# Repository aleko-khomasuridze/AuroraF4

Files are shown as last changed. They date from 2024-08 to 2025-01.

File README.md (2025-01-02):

# AuroraF4

AuroraF4 is a powerful development board based on the STM32F407VGT microcontroller, designed to provide developers with a feature-rich and compact solution for embedded system projects. This board is equipped with multiple peripherals, GPIOs, and expansion headers, making it ideal for both beginners and professionals.

## Features

- **Microcontroller**: STM32F407VGT
  - ARM Cortex-M4 processor
  - 168 MHz clock speed
  - 1 MB Flash, 192 KB SRAM
- **Interfaces**:
  - SPI, I2C, USART
  - JTAG/SWD debugging support
- **Peripherals**:
  - User-configurable LEDs (Green, Red, Yellow, Blue)
  - Reset (RST) and User (USR) buttons
  - Power input via USB-C or barrel jack
- **Expansion**:
  - Pin headers for GPIO access
  - 3.3V and GND pins available for peripherals
- **Power**:
  - Powered via USB-C or external 12V input

## Pinout Diagram

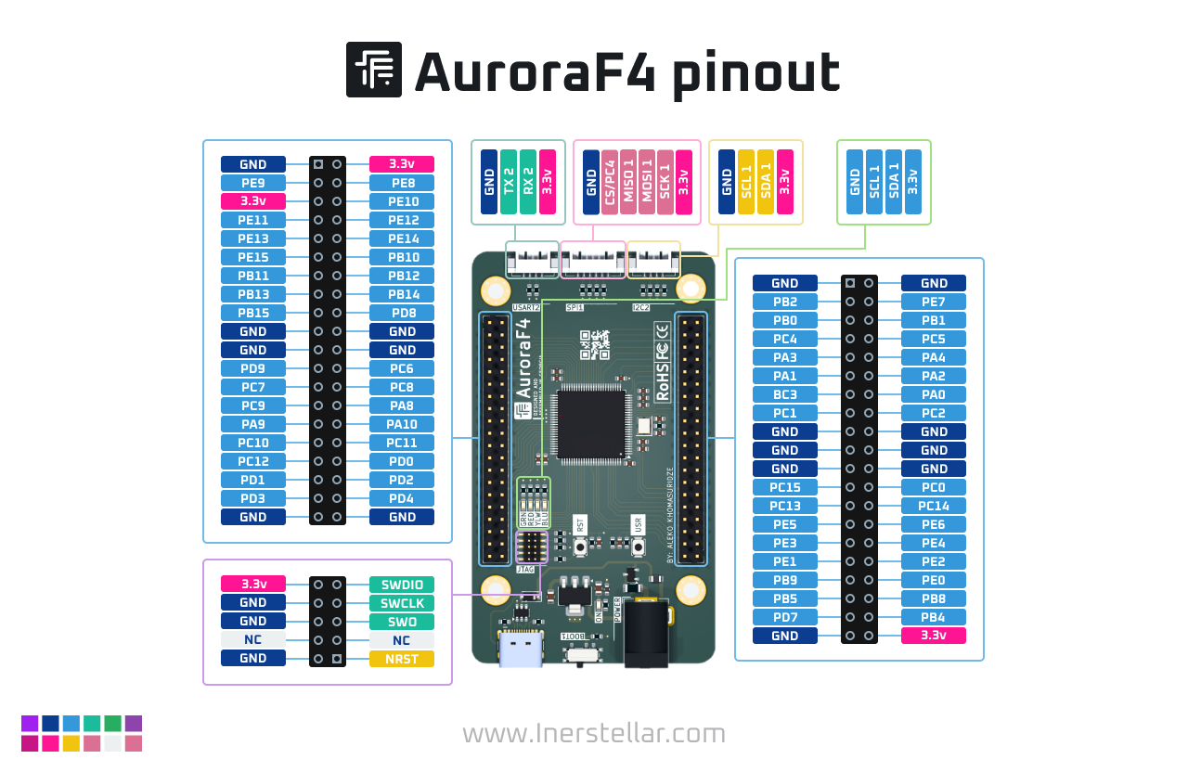
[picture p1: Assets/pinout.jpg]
AuroraF4 Pinout


Refer to the pinout diagram above for GPIO assignments and interface connections.

## PCB Design and Layout

### PCB Top View
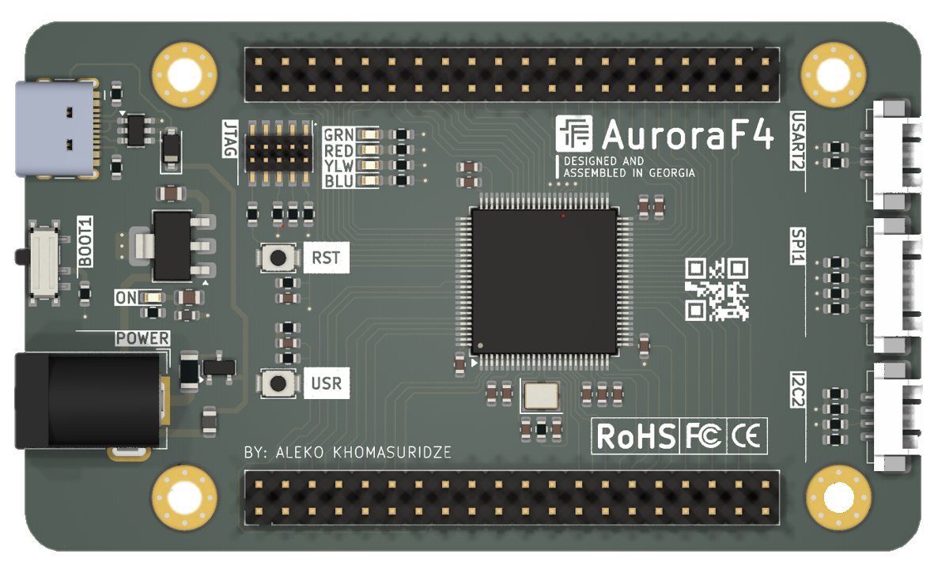
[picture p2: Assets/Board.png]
AuroraF4 PCB Layout


### 3D Render
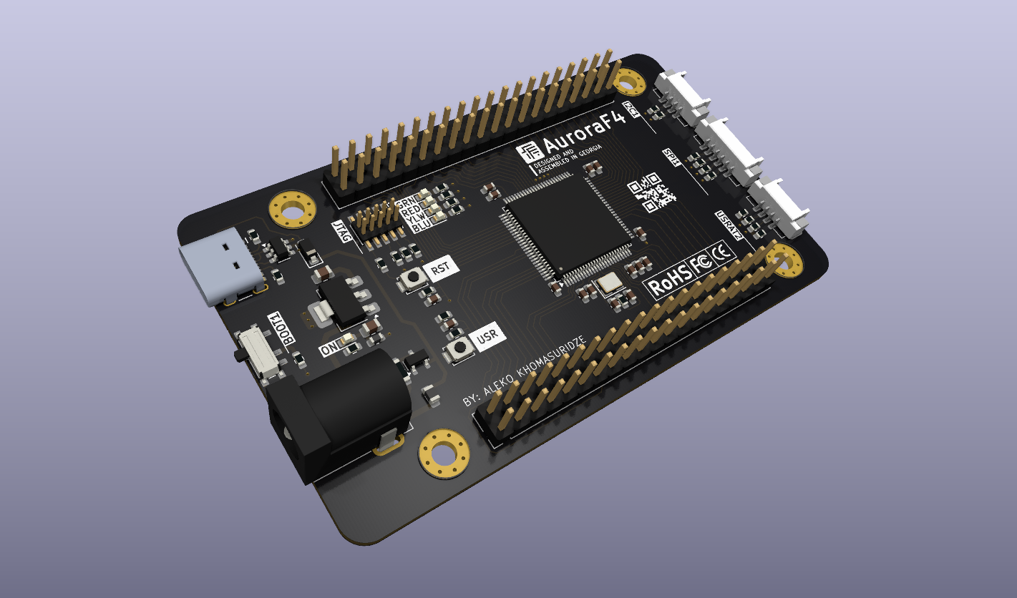
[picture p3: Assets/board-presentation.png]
AuroraF4 Render


## Getting Started

### Prerequisites

- Install [STM32CubeIDE](https://www.st.com/en/development-tools/stm32cubeide.html) for firmware development.
- Set up the STM32CubeMX tool for peripheral configuration.

### Powering the Board

1. Connect a USB-C cable to the power port.
2. Alternatively, use a 12V adapter through the barrel jack.

### Flashing Code

1. Connect the board to   your computer via USB.
2. Open STM32CubeIDE, configure your project for the STM32F407VGT.
3. Build and flash your program to the board.

### Debugging

Use the JTAG/SWD interface for debugging and programming. Ensure you have a compatible debugger like ST-Link V2.

## Applications

AuroraF4 is suitable for:
- Embedded systems prototyping
- IoT projects
- Robotics and automation
- Learning and experimentation with ARM Cortex-M4 architecture

## Resources

- [STM32F407VGT Datasheet](https://www.st.com/resource/en/datasheet/stm32f407vg.pdf)
- [STM32CubeIDE](https://www.st.com/en/development-tools/stm32cubeide.html)
- Pinout and Schematic: Refer to the `pinout.jpg` and PCB layout images in this repository.

## Credits

AuroraF4 is designed and assembled in Georgia by Aleko Khomasuridze.

---

For questions, suggestions, or contributions, feel free to open an issue or reach out.

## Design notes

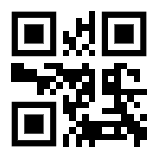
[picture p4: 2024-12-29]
Assets/Screenshot 2024-10-15 233057.png

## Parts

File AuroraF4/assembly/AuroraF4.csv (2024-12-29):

Designator | Comment | Footprint | JLCPCB Part # | Available | Orders
BOOT1 | SW_SPDT | Button_Switch_SMD:SW_SPDT_PCM12 | C221841
C1 | 4u7 | Capacitor_SMD:C_0603_1608Metric | C1705
C2,C3 | 2u2 | Capacitor_SMD:C_0603_1608Metric | C23630
C4,C5,C6,C7,C8,C9,C17,C18 | 100n | Capacitor_SMD:C_0603_1608Metric | C14663
C10 | 1u | Capacitor_SMD:C_0603_1608Metric | C1592
C11 | 10n | Capacitor_SMD:C_0603_1608Metric | C100042
C12,C13 | 12p | Capacitor_SMD:C_0603_1608Metric | C107034
C14 | 10u | Capacitor_SMD:C_0805_2012Metric | C5189822
C15 | 22u | Capacitor_SMD:C_0805_2012Metric | C29277
D1 | BLUE | LED_SMD:LED_0603_1608Metric | C72041
D2 | RED | LED_SMD:LED_0603_1608Metric | C72044
D3 | YELLOW | LED_SMD:LED_0603_1608Metric | C72038
D4,D5 | GREEN | LED_SMD:LED_0603_1608Metric | C72043
D6 | 1N4148WT | Diode_SMD:D_SOD-123 | C963381
F1 | 250mA | Fuse:Fuse_1206_3216Metric | C135328
FB1 | 600 @ 600MHz | Inductor_SMD:L_0805_2012Metric | C1017
J1 | SPI_1 | Connector_JST_XA_1.25mm:JST-XA-1.25mm SMD Horizontal 01x06
J2 | SWD | Connector_PinHeader_1.27mm:PinHeader_2x05_P1.27mm_Vertical_SMD | C598540
J3 | I2C_1 | Connector_JST_XA_1.25mm:JST-XA-1.25mm SMD Horizontal 01x04
J4 | USART_2 | Connector_JST_XA_1.25mm:JST-XA-1.25mm SMD Horizontal 01x04
J5 | USB_C_Receptacle_USB2.0_16P | USB_TYPE_C:USB_C_Receptacle_HCTL_HC-TYPE-C-16P-01A | C39832533
J7,J9 | Conn_02x20_Odd_Even | Connector_PinHeader_2.54mm:PinHeader_2x20_P2.54mm_Vertical
L1 | 39n | Inductor_SMD:L_0603_1608Metric | C74308
POWER | Barrel_Jack_MountingPin | Connector_DC_Jack:BarrelJack_GCT_DCJ200-10-A_Horisontal | C319099
Q1 | AO3401A | Package_TO_SOT_SMD:SOT-23 | C347476
R1 | 10k | Resistor_SMD:R_0603_1608Metric | C25804
R2 | 47r | Resistor_SMD:R_0603_1608Metric | C23182
R4,R5 | 4.7k | Resistor_SMD:R_0603_1608Metric | C105428
R6 | 100R | Resistor_SMD:R_0603_1608Metric | C23345
R7,R8,R9,R10,R13,R14,R15,R16,R20,R21,R22,R23 | 22r | Resistor_SMD:R_0603_1608Metric | C23345
R11,R12 | 2.2k | Resistor_SMD:R_0603_1608Metric | C4190
R17,R18 | 5.1k | Resistor_SMD:R_0603_1608Metric | C23186
R19 | 330r | Resistor_SMD:R_0603_1608Metric | C23138
R24,R25,R26,R27 | 1k | Resistor_SMD:R_0603_1608Metric | C25804
RST | SW_Push | Button_Switch_SMD:SW_SPST_B3U-1000P | C843666
U1 | STM32F407VGTx | Package_QFP:LQFP-100_14x14mm_P0.5mm | C12345
U3 | USBLC6-2SC6 | Package_TO_SOT_SMD:SOT-23-6 | C7519
U4 | AMS1117-3.3 | Package_TO_SOT_SMD:SOT-223-3_TabPin2 | C347222
USR | SW_Push | Button_Switch_SMD:SW_SPST_B3U-1000P | C843666
Y1 | 16MHz | Crystal:Crystal_SMD_3225-4Pin_3.2x2.5mm | C5917307

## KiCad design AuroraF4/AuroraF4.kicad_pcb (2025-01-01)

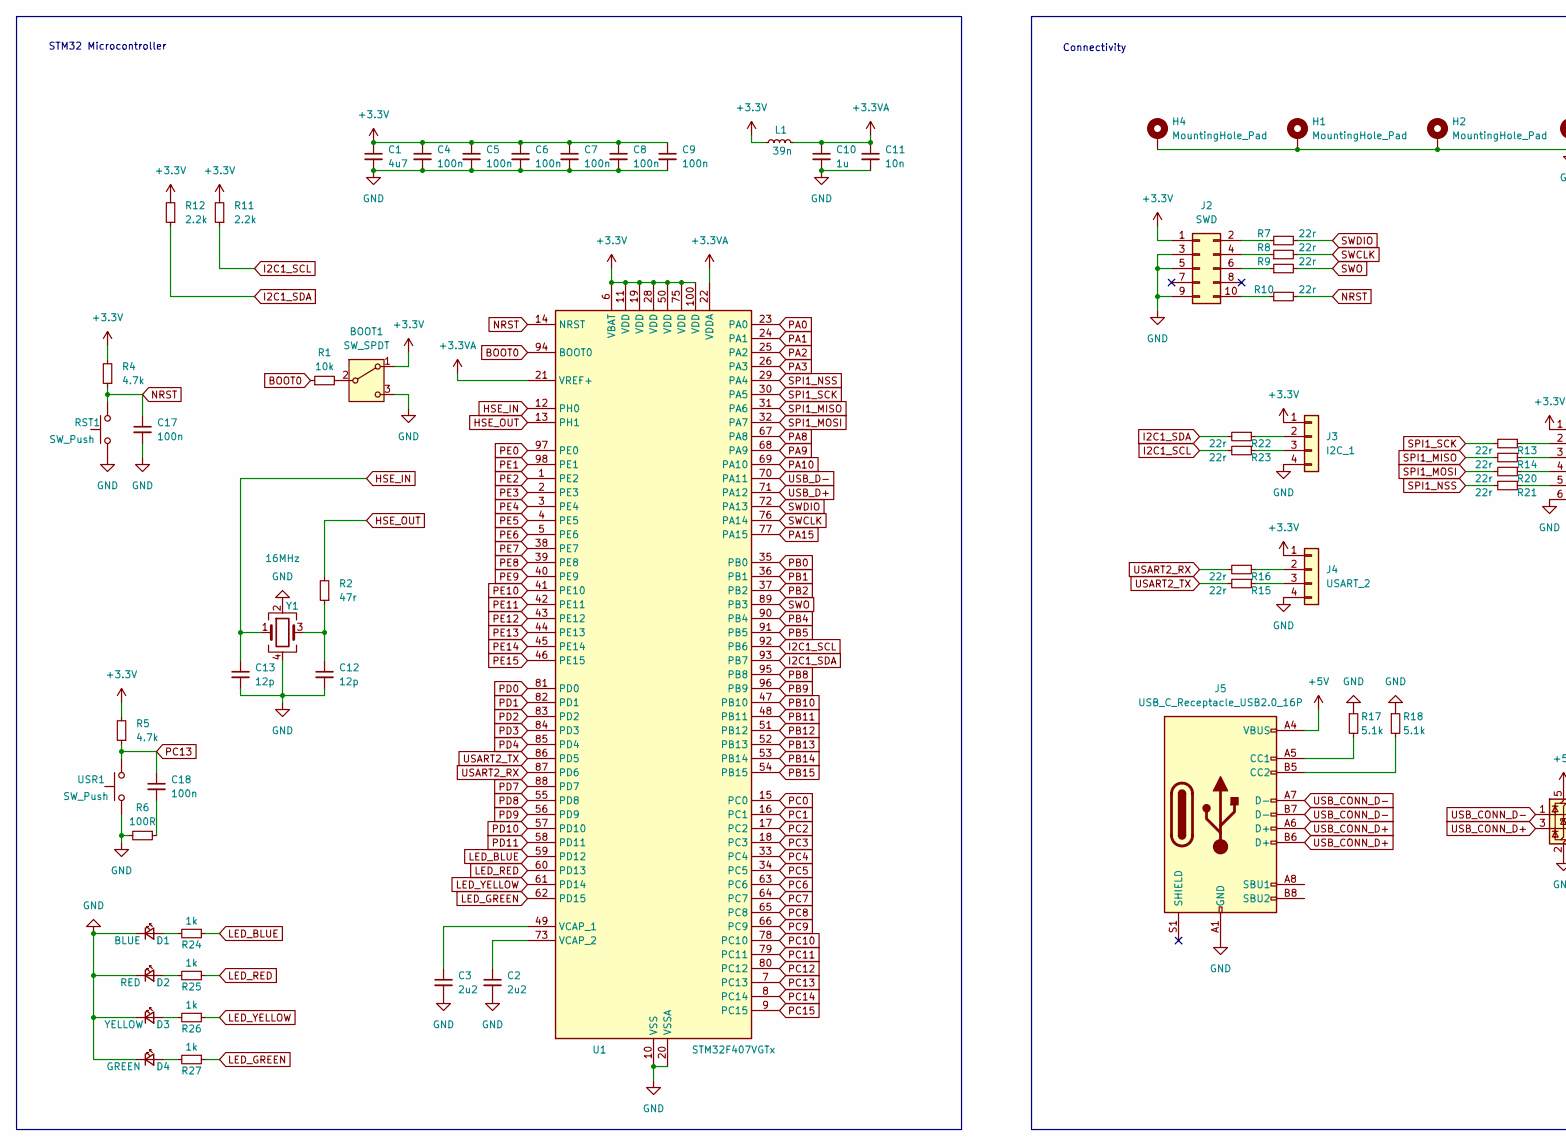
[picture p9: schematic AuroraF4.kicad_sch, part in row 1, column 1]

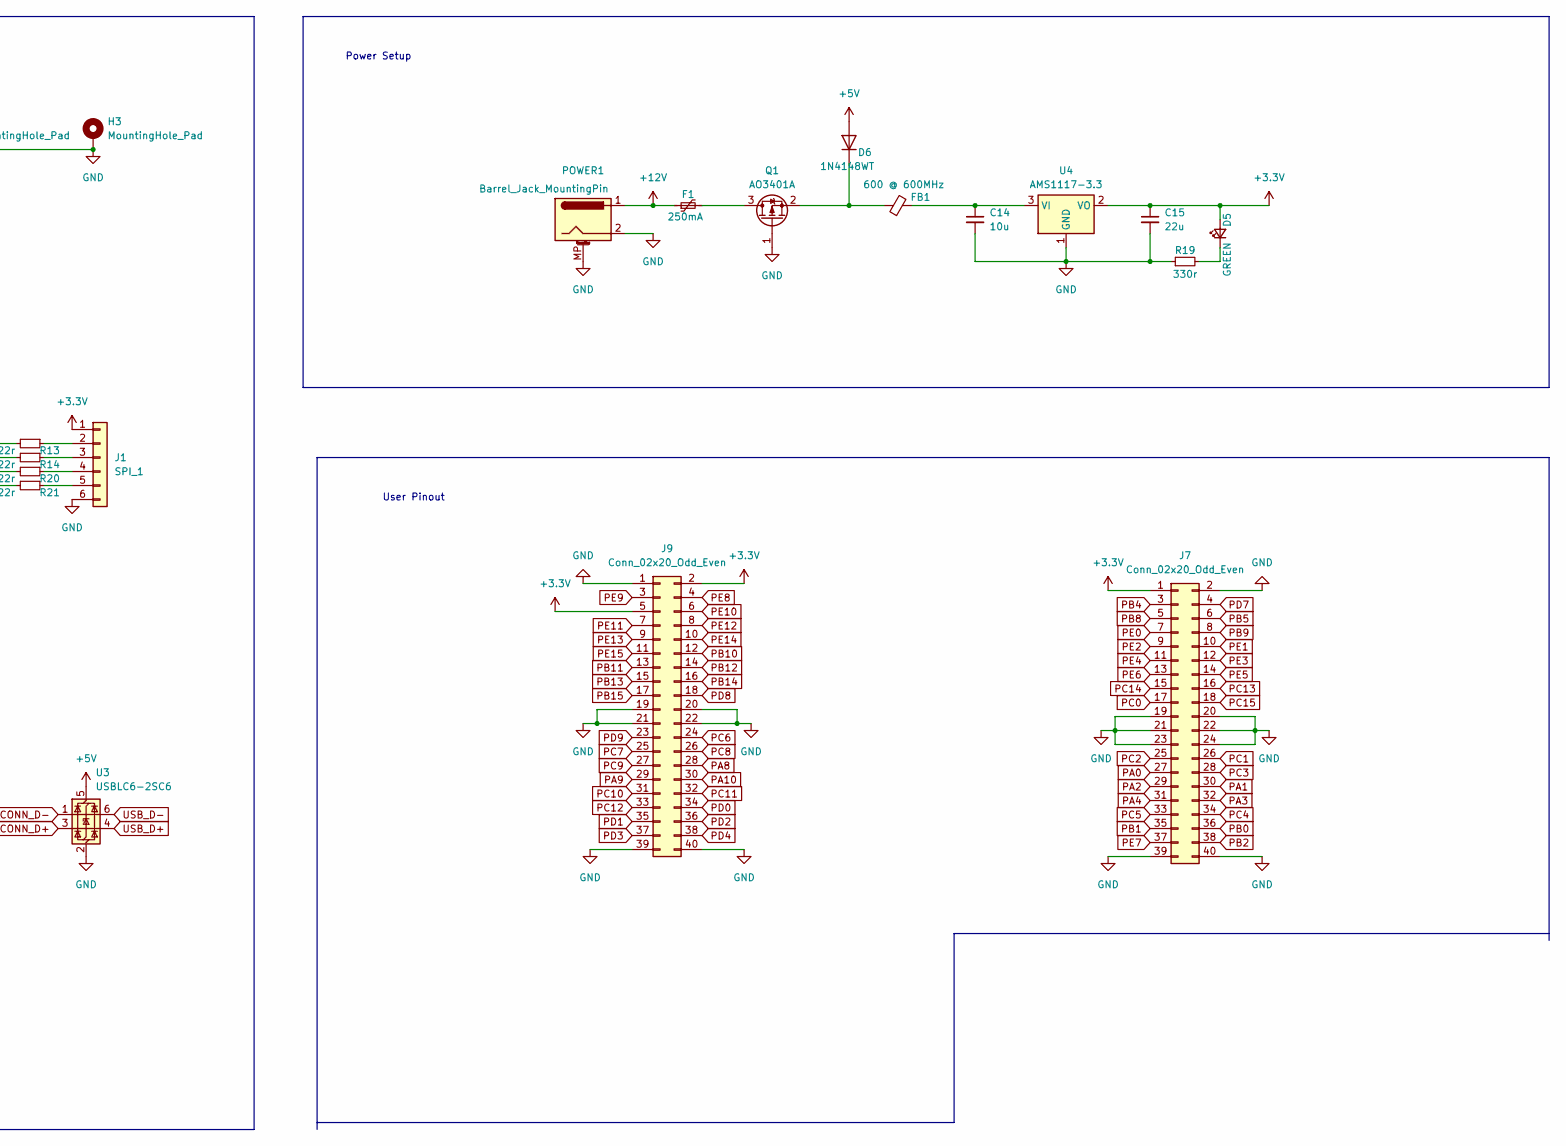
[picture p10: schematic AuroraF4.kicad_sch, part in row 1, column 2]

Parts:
BOOT1: SW_SPDT; SW_SPDT_PCM12; LCSC Part # C221841
C1: 4u7; C_0603_1608Metric; LCSC Part # C1705
C2, C3: 2u2; C_0603_1608Metric; LCSC Part # C23630
C4, C5, C6, C7, C8, C9, C17, C18: 100n; C_0603_1608Metric; LCSC Part # C14663
C10: 1u; C_0603_1608Metric; LCSC Part # C1592
C11: 10n; C_0603_1608Metric; LCSC Part # C100042
C12, C13: 12p; C_0603_1608Metric; LCSC Part # C107034
C14: 10u; C_0805_2012Metric; LCSC Part # C5189822
C15: 22u; C_0805_2012Metric; LCSC Part # C29277
D1: BLUE; LED_0603_1608Metric; LCSC Part # C72041
D2: RED; LED_0603_1608Metric; LCSC Part # C72044
D3: YELLOW; LED_0603_1608Metric; LCSC Part # C72038
D4, D5: GREEN; LED_0603_1608Metric; LCSC Part # C72043
D6: 1N4148WT; D_SOD-123; LCSC Part # C963381
F1: 250mA; Fuse_1206_3216Metric; LCSC Part # C135328
FB1: 600 @ 600MHz; L_0805_2012Metric; LCSC Part # C1017
H1, H2, H3, H4: MountingHole_Pad; MountingHole_3.2mm_M3_Pad_Via
J1: SPI_1; JST-XA-1.25mm SMD Horizontal 01x06
J2: SWD; PinHeader_2x05_P1.27mm_Vertical_SMD; LCSC Part # C598540
J3: I2C_1; JST-XA-1.25mm SMD Horizontal 01x04
J4: USART_2; JST-XA-1.25mm SMD Horizontal 01x04
J5: USB_C_Receptacle_USB2.0_16P; USB_C_Receptacle_HCTL_HC-TYPE-C-16P-01A; LCSC Part # C39832533
J7, J9: Conn_02x20_Odd_Even; PinHeader_2x20_P2.54mm_Vertical
L1: 39n; L_0603_1608Metric; LCSC Part # C74308
POWER1: Barrel_Jack_MountingPin; BarrelJack_GCT_DCJ200-10-A_Horisontal; LCSC Part # C319099
Q1: AO3401A; SOT-23; LCSC Part # C347476
R1: 10k; R_0603_1608Metric; LCSC Part # C25804
R2: 47r; R_0603_1608Metric; LCSC Part # C23182
R4, R5: 4.7k; R_0603_1608Metric; LCSC Part # C105428
R6: 100R; R_0603_1608Metric; LCSC Part # C23345
R7, R8, R9, R10, R13, R14, R15, R16, R20, R21, R22, R23: 22r; R_0603_1608Metric; LCSC Part # C23345
R11, R12: 2.2k; R_0603_1608Metric; LCSC Part # C4190
R17, R18: 5.1k; R_0603_1608Metric; LCSC Part # C23186
R19: 330r; R_0603_1608Metric; LCSC Part # C23138
R24, R25, R26, R27: 1k; R_0603_1608Metric; LCSC Part # C25804
RST1: SW_Push; SW_SPST_B3U-1000P; LCSC Part # C843666
U1: STM32F407VGTx; LQFP-100_14x14mm_P0.5mm; LCSC Part # C12345
U3: USBLC6-2SC6; SOT-23-6; LCSC Part # C7519
U4: AMS1117-3.3; SOT-223-3_TabPin2; LCSC Part # C347222
USR1: SW_Push; SW_SPST_B3U-1000P; LCSC Part # C843666
Y1: 16MHz; Crystal_SMD_3225-4Pin_3.2x2.5mm; LCSC Part # C5917307

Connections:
+3.3V: BOOT1.1 (A), C1.1, C4.1, C5.1, C6.1, C7.1, C8.1, C9.1, C15.1, D5.2 (A), J1.1, J2.1, J3.1, J4.1, J7.1, J9.2, J9.5, L1.1, R4.2, R5.2, R11.2, R12.2, U1.6 (VBAT), U1.11 (VDD), U1.19 (VDD), U1.28 (VDD), U1.50 (VDD), U1.75 (VDD), U1.100 (VDD), U4.2 (VO)
+3.3VA: C10.1, C11.1, L1.2, U1.21 (VREF+), U1.22 (VDDA)
+5V: D6.2 (A), J5.A4 (VBUS), J5.A9 (VBUS), J5.B4 (VBUS), J5.B9 (VBUS), U3.5 (VBUS)
+12V: F1.1, POWER1.1; also elsewhere on the board
BOOT0: R1.1, U1.94 (BOOT0)
GND: BOOT1.3 (C), C1.2, C2.2, C3.2, C4.2, C5.2, C6.2, C7.2, C8.2, C9.2, C10.2, C11.2, C12.2, C13.2, C14.2, C15.2, C17.2, D1.1 (K), D2.1 (K), D3.1 (K), D4.1 (K), H1.1, H2.1, H3.1, H4.1, J1.6, J2.3, J2.5, J2.9, J3.4, J4.4, J5.A1 (GND), J5.A12 (GND), J5.B1 (GND), J5.B12 (GND), J7.2, J7.19, J7.20, J7.21, J7.22, J7.23, J7.24, J7.39, J7.40, J9.1, J9.19, J9.20, J9.21, J9.22, J9.39, J9.40, POWER1.2, POWER1.MP (MountPin), Q1.1 (G), R6.2, R17.1, R18.1, R19.1, RST1.1, U1.10 (VSS), U1.20 (VSSA), U1.27 (VSS), U1.74 (VSS), U1.99 (VSS), U3.2 (GND), U4.1 (GND), USR1.1, Y1.2, Y1.4; also elsewhere on the board
HSE_IN: C13.1, U1.12 (PH0), Y1.1
HSE_OUT: R2.2, U1.13 (PH1)
I2C1_SCL: R11.1, R23.2, U1.92 (PB6)
I2C1_SDA: R12.1, R22.2, U1.93 (PB7)
LED_BLUE: R24.1, U1.59 (PD12)
LED_GREEN: R27.1, U1.62 (PD15)
LED_RED: R25.1, U1.60 (PD13)
LED_YELLOW: R26.1, U1.61 (PD14)
NRST: C17.1, R4.1, R10.2, RST1.2, U1.14 (NRST); also elsewhere on the board
unnamed: BOOT1.2 (B), R1.2
unnamed: C12.1, R2.1, Y1.3
unnamed: C18.2, R6.1
unnamed: D1.2 (A), R24.2
unnamed: D2.2 (A), R25.2
unnamed: D3.2 (A), R26.2
unnamed: D4.2 (A), R27.2
unnamed: D5.1 (K), R19.2
unnamed: D6.1 (K), FB1.1, Q1.2 (S)
unnamed: J1.2, R13.1
unnamed: J1.3, R14.1
unnamed: J1.4, R20.1
unnamed: J1.5, R21.1
unnamed: J2.2, R7.1
unnamed: J2.4, R8.1
unnamed: J2.6, R9.1
unnamed: J2.10, R10.1
unnamed: J3.2, R22.1
unnamed: J3.3, R23.1
unnamed: J4.2, R16.1
unnamed: J4.3, R15.1
unnamed: J5.A5 (CC1), R17.2
unnamed: J5.B5 (CC2), R18.2
unnamed: F1.2, Q1.3 (D)
unnamed: C3.1, U1.49 (VCAP_1)
unnamed: C2.1, U1.73 (VCAP_2)
unnamed: C14.1, FB1.2, U4.3 (VI)
PA0: J7.27, U1.23 (PA0)
PA1: J7.30, U1.24 (PA1)
PA2: J7.29, U1.25 (PA2)
PA3: J7.32, U1.26 (PA3)
PA4: J7.31
PA8: J9.28, U1.67 (PA8)
PA9: J9.29, U1.68 (PA9)
PA10: J9.30, U1.69 (PA10)
PA15: U1.77 (PA15)
PB0: J7.36, U1.35 (PB0)
PB1: J7.35, U1.36 (PB1)
PB2: J7.38, U1.37 (PB2)
PB4: J7.3, U1.90 (PB4)
PB5: J7.6, U1.91 (PB5)
PB8: J7.5, U1.95 (PB8)
PB9: J7.8, U1.96 (PB9)
PB10: J9.12, U1.47 (PB10)
PB11: J9.13, U1.48 (PB11)
PB12: J9.14, U1.51 (PB12)
PB13: J9.15, U1.52 (PB13)
PB14: J9.16, U1.53 (PB14)
PB15: J9.17, U1.54 (PB15)
PC0: J7.17, U1.15 (PC0)
PC1: J7.26, U1.16 (PC1)
PC2: J7.25, U1.17 (PC2)
PC3: J7.28, U1.18 (PC3)
PC4: J7.34, U1.33 (PC4)
PC5: J7.33, U1.34 (PC5)
PC6: J9.24, U1.63 (PC6)
PC7: J9.25, U1.64 (PC7)
PC8: J9.26, U1.65 (PC8)
PC9: J9.27, U1.66 (PC9)
PC10: J9.31, U1.78 (PC10)
PC11: J9.32, U1.79 (PC11)
PC12: J9.33, U1.80 (PC12)
PC13: C18.1, J7.16, R5.1, U1.7 (PC13), USR1.2; also elsewhere on the board
PC14: J7.15, U1.8 (PC14)
PC15: J7.18, U1.9 (PC15)
PD0: J9.34, U1.81 (PD0)
PD1: J9.35, U1.82 (PD1)
PD2: J9.36, U1.83 (PD2)
PD3: J9.37, U1.84 (PD3)
PD4: J9.38, U1.85 (PD4)
PD7: J7.4, U1.88 (PD7)
PD8: J9.18, U1.55 (PD8)
PD9: J9.23, U1.56 (PD9)
PD10: U1.57 (PD10)
PD11: U1.58 (PD11)
PE0: J7.7, U1.97 (PE0)
PE1: J7.10, U1.98 (PE1)
PE2: J7.9, U1.1 (PE2)
PE3: J7.12, U1.2 (PE3)
PE4: J7.11, U1.3 (PE4)
PE5: J7.14, U1.4 (PE5)
PE6: J7.13, U1.5 (PE6)
PE7: J7.37, U1.38 (PE7)
PE8: J9.4, U1.39 (PE8)
PE9: J9.3, U1.40 (PE9)
PE10: J9.6, U1.41 (PE10)
PE11: J9.7, U1.42 (PE11)
PE12: J9.8, U1.43 (PE12)
PE13: J9.9, U1.44 (PE13)
PE14: J9.10, U1.45 (PE14)
PE15: J9.11, U1.46 (PE15)
SPI1_MISO: R14.2, U1.31 (PA6)
SPI1_MOSI: R20.2, U1.32 (PA7)
SPI1_NSS: R21.2, U1.29 (PA4)
SPI1_SCK: R13.2, U1.30 (PA5)
SWCLK: R8.2, U1.76 (PA14)
SWDIO: R7.2, U1.72 (PA13)
SWO: R9.2, U1.89 (PB3)
USART2_RX: R16.2, U1.87 (PD6)
USART2_TX: R15.2, U1.86 (PD5)
USB_CONN_D+: J5.A6 (D+), J5.B6 (D+), U3.3 (I/O2)
USB_CONN_D-: J5.A7 (D-), J5.B7 (D-), U3.1 (I/O1)
USB_D+: U1.71 (PA12), U3.4 (I/O2)
USB_D-: U1.70 (PA11), U3.6 (I/O1)

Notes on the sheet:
Power Setup
STM32 Microcontroller
Connectivity
User Pinout

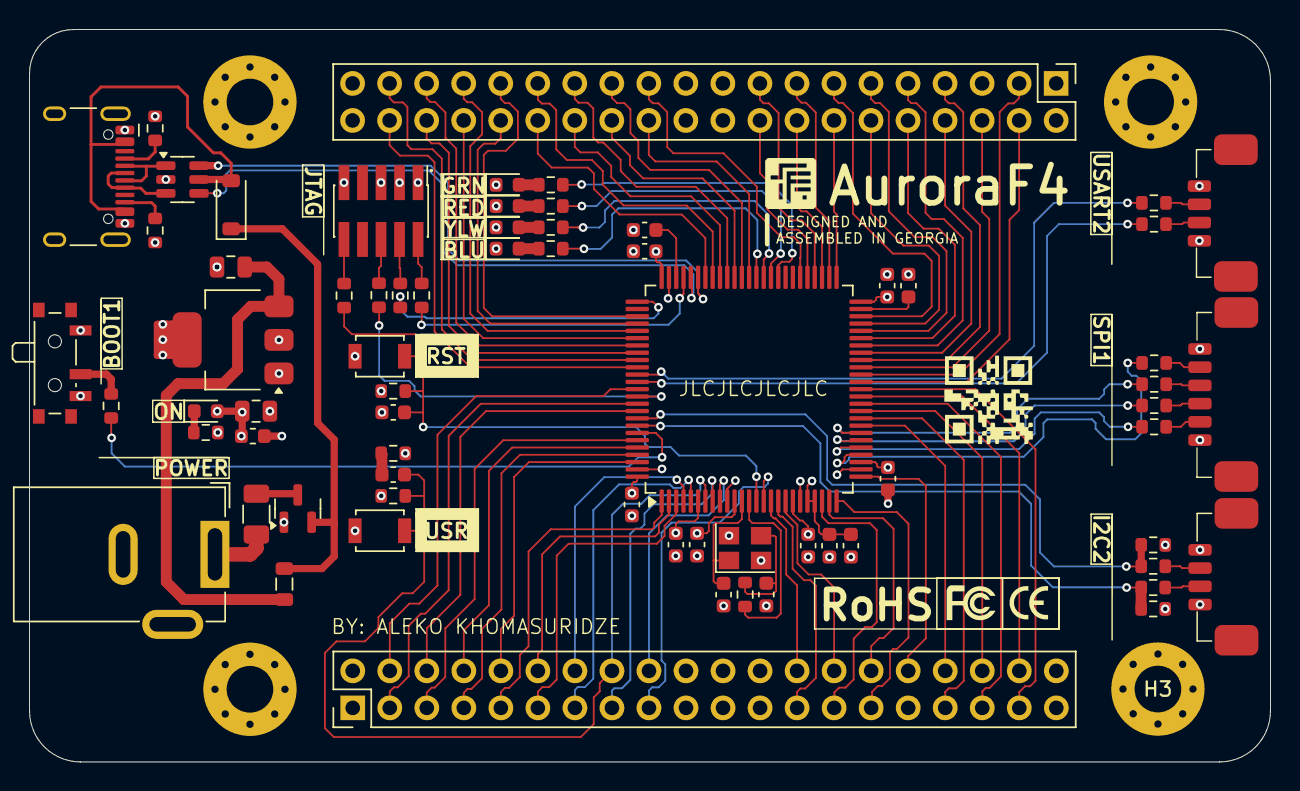
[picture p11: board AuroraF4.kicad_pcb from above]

Board: 4 copper layers, 85.1 x 50.2 mm, 72 parts (0 on the bottom side), 115 nets.

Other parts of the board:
POWER: Barrel_Jack_MountingPin; BarrelJack_GCT_DCJ200-10-A_Horisontal
RST: SW_Push; SW_SPST_B3U-1000P
USR: SW_Push; SW_SPST_B3U-1000P

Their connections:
+12V: POWER.1; also elsewhere on the board
GND: POWER.2, RST.1, USR.1; also elsewhere on the board
NRST: RST.2; also elsewhere on the board
PC13: USR.2; also elsewhere on the board

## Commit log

2024-08-04 initilized PCB Prj
    [AuroraF4_v1.0.0.PrjPcb, LQFP100-14x14mm.step, QFP50P1600X1600X160-100N.PcbLib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]
2024-08-07 Added reset boot I2C, SPI, UART, ETH to Sch
    [main.SchDoc]
2024-08-07 added indicator lights to uart
    [0603 Blue.step, main.SchDoc]
2024-08-08 added Indicator LED and 2x20 male header to Sch
    [2x20_Male_Header.step, AuroraF4_v1.0.0.PrjPcb, main.SchDoc]
2024-08-08 PCB Update
    [main.SchDoc]
2024-08-10 added stlink support to Sch and fixed layout of components on PCB
    [User Library-2_54mm Male Header (4x2).STEP, main.SchDoc]
2024-08-10 createdd logo for board
2024-08-10 added some silk screen decorations to PCB
    [main.SchDoc]
2024-08-11 started routing traces
    [main.SchDoc]
2024-08-11 finished routing all the tracks
    [main.SchDoc]
2024-08-12 started adding polygons to PCB and fixed some silk screen
2024-08-12 added silk screens on the top of the board
2024-08-13 finalized board v1.0.0
    [main.GBL, main.GBO, main.GBP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]
2024-08-13 fixed USB-C pads
    [AuroraF4_v1.0.0.PrjPcb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]
2024-08-22 updated pcb and generated bom file
    [main.SchDoc]
2024-12-29 complete AuroraF4 Board refactor
    [0603 Blue.step, 2x20_Male_Header.step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]
2025-01-01 fixed 3D models
    [AuroraF4.kicad_pcb]
